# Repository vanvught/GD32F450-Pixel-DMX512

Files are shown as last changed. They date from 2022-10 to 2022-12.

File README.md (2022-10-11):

#GD32F450 Pixel DMX512

Features: 

- 16x 4 Universes pixel output
- 2x  1 Universe DMX output
- EEPROM for storing the configuration
- 1x I2C (display)
- 1x SPI
- 2x UART (WiFi , Bluetooth)

Firmware: [https://github.com/vanvught/GD32F450VI-DMX512-PIXEL](https://github.com/vanvught/GD32F450VI-DMX512-PIXEL)

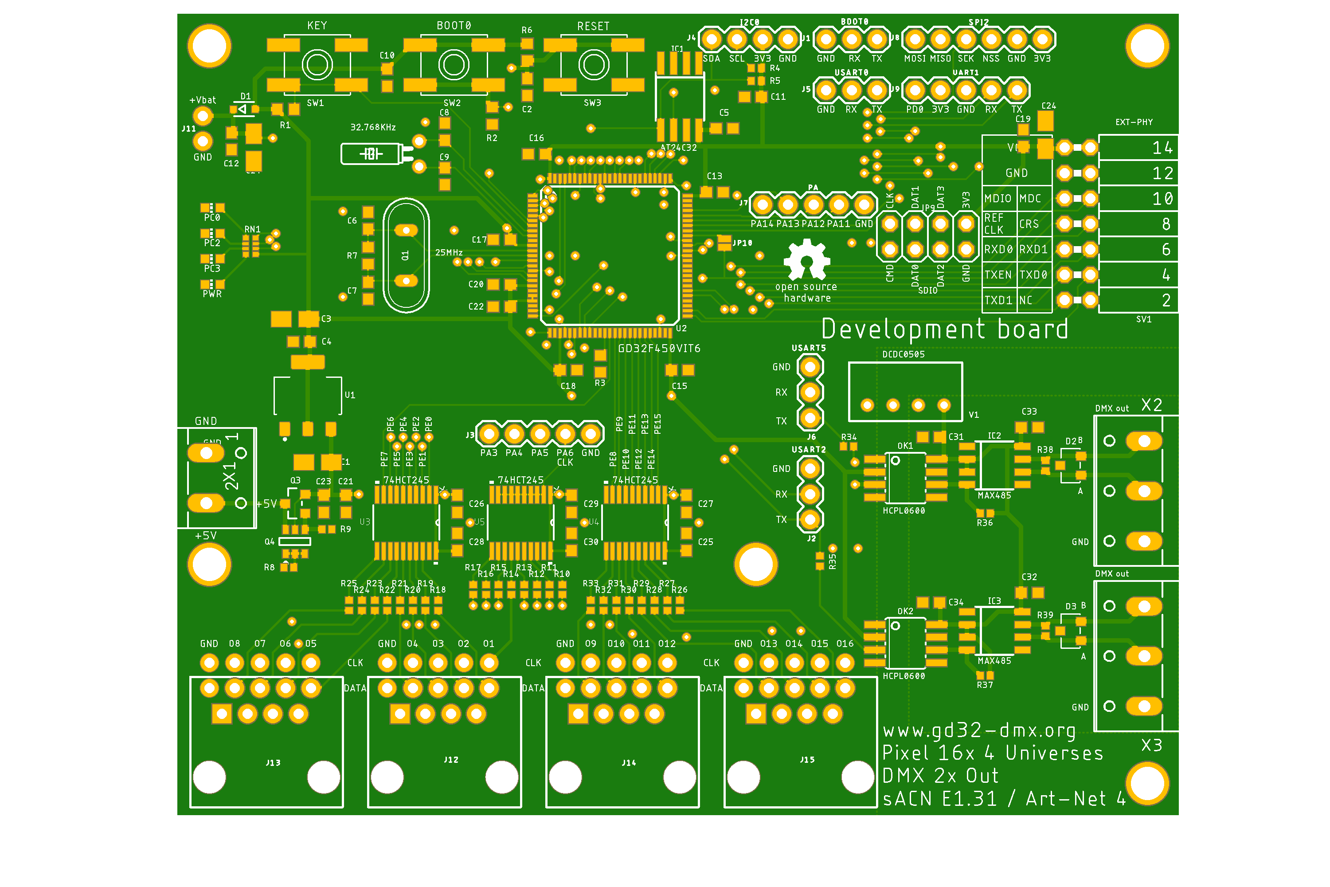
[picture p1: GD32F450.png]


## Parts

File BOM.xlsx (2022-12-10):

Qty | Designator | Footprint | Comment | LCSC Part #
4 | C1, C3, C14, C24 | A/3216-18R | 10uF | C7171
26 | C2, C4, C5, C10, C11, C12, C13, C15, C16, C17, C18, C19, C20, C22,C21, C23 , C25, C26, C27, C28, C29, C30, C31, C32, C33, C34 | C0603 | 100n | C14663
2 | C6, C7 | C0603 | 20pF | C1648
2 | C8, C9 | C0603 | 10pF | C1634
1 | D1 | SOD323-R | 1N5819 | C191023
2 | D2, D3 | SOT23-3 | PSM712-LF-T7 | C32677
1 | IC1 | SO-08M | AT24C32 | C2688466
2 | IC2, IC3 | D_R-PDSO-G8 | MAX485 | C23492
4 | LED1, LED2 , LED3, LED4 | CHIP-LED0603 | CHIP-LED0603 | C72043
2 | OK1, OK2 | SOIC08 | HCPL0600 | C393524
1 | Q3 | DIODES_INC._DMG2305UX-13_0 | DMG2305UX | C150470
1 | Q4 | DIODES_DMMT5401-7-F_0 | DMMT5401-7-F_0_0 | C154733
4 | R1, R2, R3, R6 | R0603 | 10K | C25804
24 | R10, R11, R12, R13, R14, R15, R16, R17, R18, R19, R20, R21, R22, R23, R24, R25, R26, R27, R28, R29, R30, R31, R32, R33 | R0402 | 100 | C25076
2 | R38, R39 | R0402 | 120 | C25079
2 | R34, R35 | R0402 | 470 | C25117
4 | R4, R5, R36, R37 | R0402 | 4K7 | C25900
1 | R7 | R0603 | 1M | C22935
1 | R8 | R0402 | 10K | C25744
1 | R9 | R0402 | 47K | C25792
1 | RN1 | 4X0402ARV341 | 2K | C44891
3 | SW1, SW2, SW3 | EVQ-Q2 | SPST 6*6mm Tactile Switch | C221880
1 | U1 | SOT23-5 | AMS1117-3.3 | C6186
1 | U2 | LQFP100 | GD32F450VIT6 | C98441
2 | U3, U4, U5 | PW20 | 74HCT245 | C10910
95

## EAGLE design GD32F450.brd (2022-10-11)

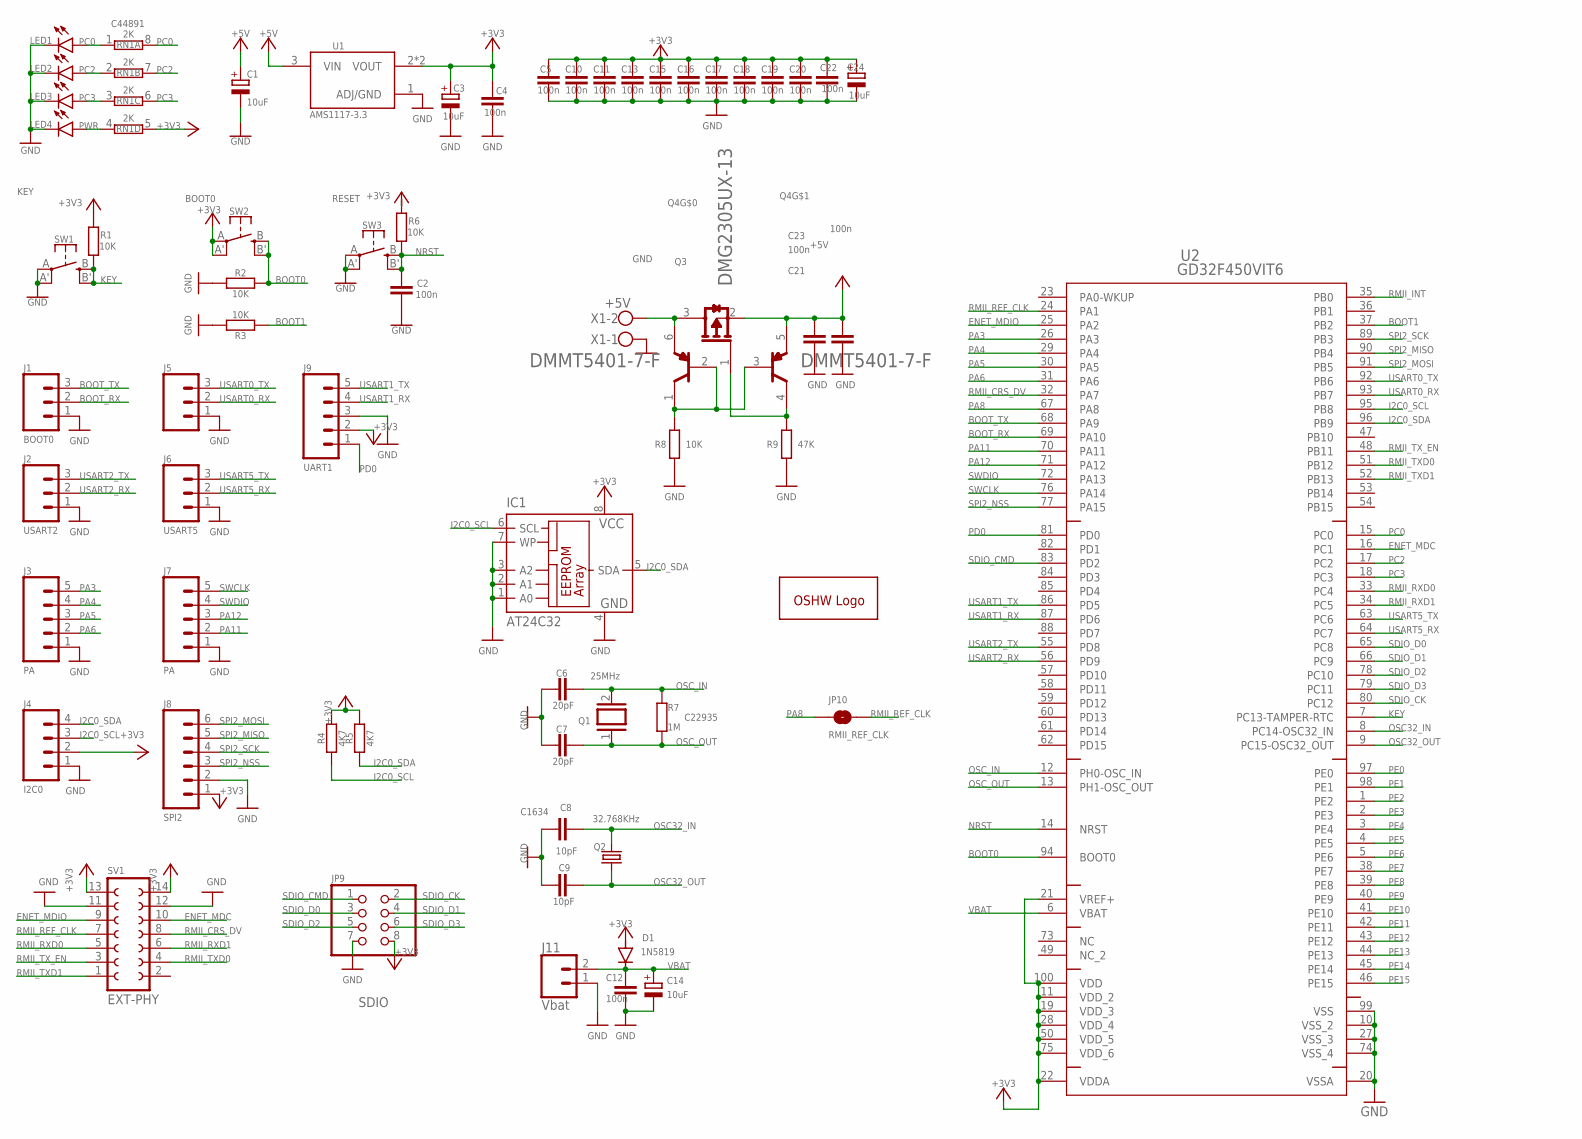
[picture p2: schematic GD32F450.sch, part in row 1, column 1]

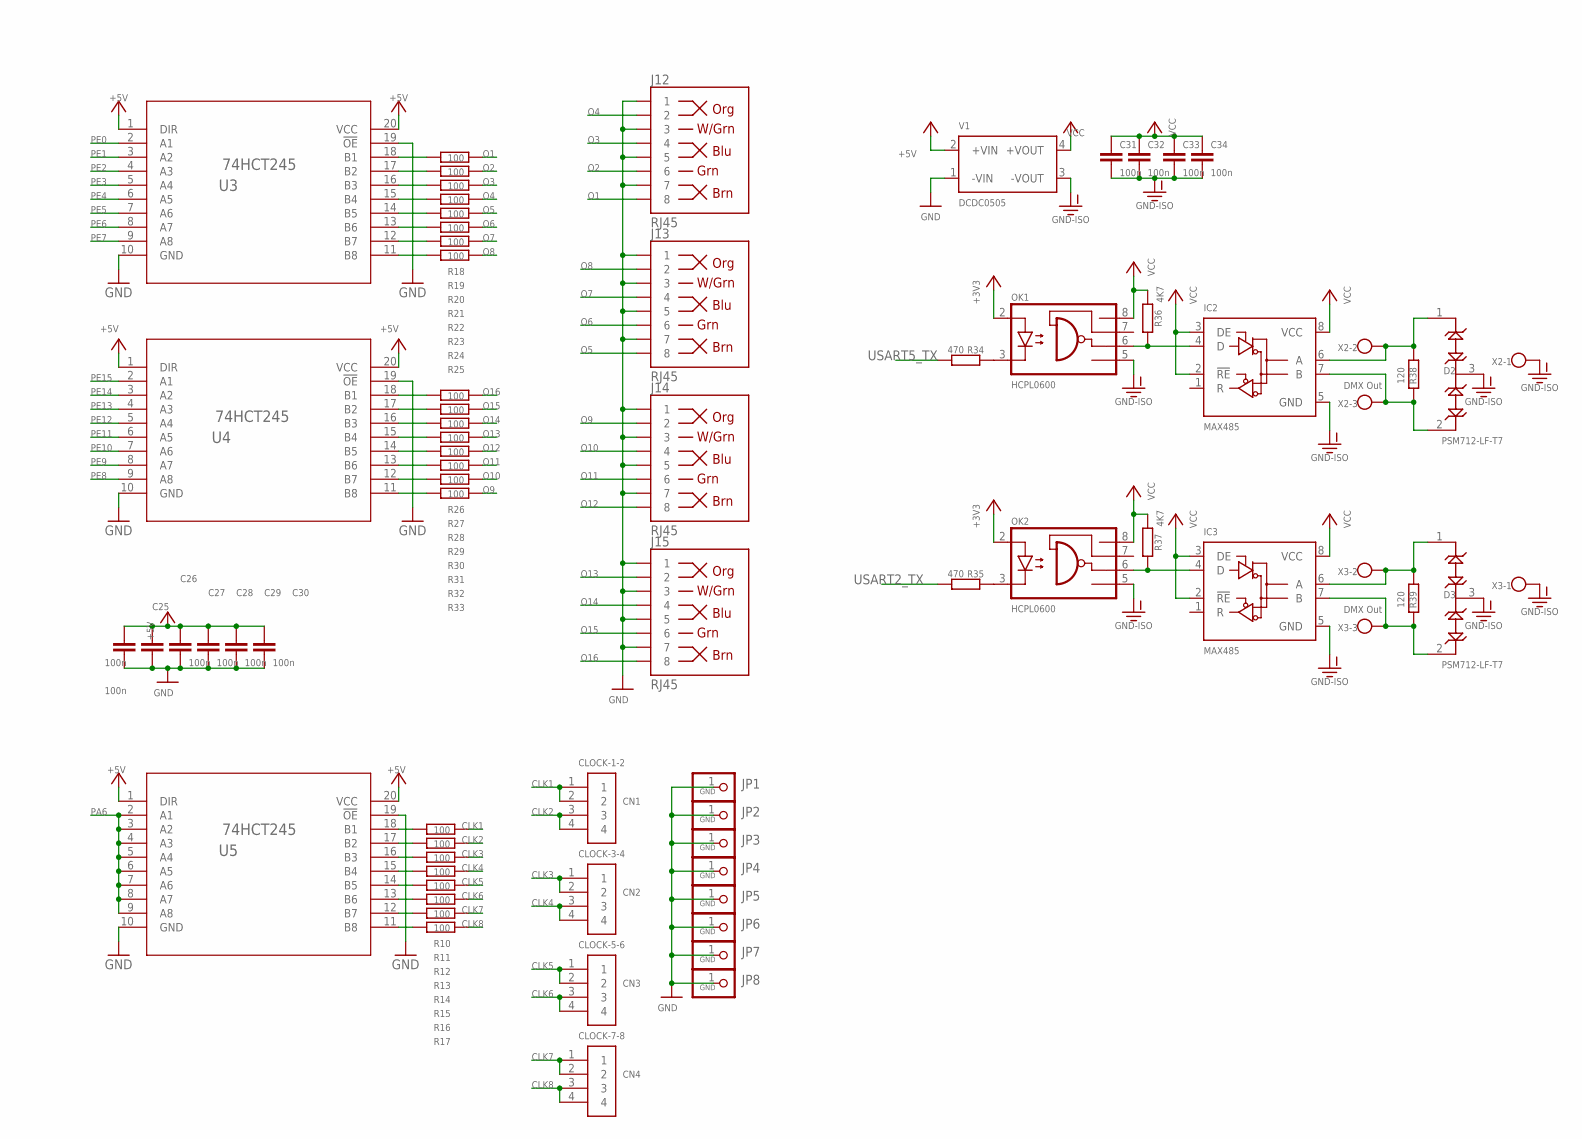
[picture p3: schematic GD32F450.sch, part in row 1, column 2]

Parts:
C1, C3, C14, C24: 10uF; A/3216-18R; JLCPCB C7171
C2, C4, C5, C10, C11, C12, C13, C15, C16, C17, C18, C19, C20, C22, C25, C26, C27, C28, C29, C30, C31, C32, C33, C34: 100n; C0603; JLCPCB C14663
C6, C7: 20pF; C0603; JLCPCB C1648
C8, C9: 10pF; C0603; JLCPCB C1634
C21, C23: 100n; C0603
CN1: CLOCK-1-2; 1X04-CLEANBIG
CN2: CLOCK-3-4; 1X04-CLEANBIG
CN3: CLOCK-5-6; 1X04-CLEANBIG
CN4: CLOCK-7-8; 1X04-CLEANBIG
D1: 1N5819; SOD323-R; JLCPCB C191023
D2, D3: PSM712-LF-T7; SOT23-3; JLCPCB C32677
GOLD_ORB_SM1: OSHWLOGOLOGO5MM; OSHW_5MM
IC1: AT24C32; SO-08M
IC2, IC3: MAX485; D_R-PDSO-G8; JLCPCB C23492
J1: BOOT0; 1X03
J2: USART2; 1X03
J3, J7: PA; 1X05
J4: I2C0; 1X04
J5: USART0; 1X03
J6: USART5; 1X03
J8: SPI2; 1X06
J9: UART1; 1X05
J11: Vbat; 1X02_NO_SILK
J12, J13, J14, J15: RJ45; RJ45-8
JP1, JP2, JP3, JP4, JP5, JP6, JP7, JP8: GND; 1X01-CLEANBIG
JP9: SDIO; 2X04
JP10: RMII_REF_CLK; SMT-JUMPER_2_NO_NO-SILK
LED1: PC0; CHIP-LED0603
LED2: PC2; CHIP-LED0603
LED3: PC3; CHIP-LED0603
LED4: PWR; CHIP-LED0603
OK1, OK2: HCPL0600; SOIC08; JLCPCB C393524
Q1: 25MHz; QS
Q2: 32.768KHz; TC26H
Q3: DMG2305UX; DIODES_INC._DMG2305UX-13_0
Q4: DMMT5401; DIODES_DMMT5401-7-F_0
R1, R2, R3, R6: 10K; R0603; JLCPCB C25804
R4, R5: 4K7; R0402; JLCPCB C23162
R7: 1M; R0603; JLCPCB C22935
R8: 10K; R0402
R9: 47K; R0402
R10, R11, R12, R13, R14, R15, R16, R17, R18, R19, R20, R21, R22, R23, R24, R25, R26, R27, R28, R29, R30, R31, R32, R33: 100; R0402
R34, R35: 470; R0402; JLCPCB C25117
R36, R37: 4K7; R0402; JLCPCB C275348
R38, R39: 120; R0402; JLCPCB C25079
RN1: 2K; 4X0402ARV341; JLCPCB C44891
SV1: EXT-PHY; FE07-2W
SW1: KEY; EVQ-Q2
SW2: BOOT0; EVQ-Q2; JLCPCB C221880
SW3: RESET; EVQ-Q2
U1: AMS1117-3.3; SOT229P700X180-4N
U2: GD32F450VIT6; LQFP100
U3, U4, U5: 74HCT245; PW20
V1: DCDC0505; TME
X1: +5V; W237-102
X2, X3: DMX Out; W237-103

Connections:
+3V3: C3.+, C4.1, C5.1, C10.1, C11.1, C13.1, C15.1, C16.1, C17.1, C18.1, C19.1, C20.1, C22.1, C24.+, D1.A, IC1.8 (VCC), J4.2, J8.1, J9.2, JP9.8, OK1.2 (A), OK2.2 (A), R1.2, R4.2, R5.2, R6.2, RN1.5 (2), SV1.13, SV1.14, SW2.A, SW2.A' (P1), U1.2 (VOUT), U1.4 (VOUT), U2.11 (VDD_2), U2.19 (VDD_3), U2.21 (VREF+), U2.22 (VDDA), U2.28 (VDD_4), U2.50 (VDD_5), U2.75 (VDD_6), U2.100 (VDD)
+5V: C1.+, C21.1, C23.1, C25.1, C26.1, C27.1, C28.1, C29.1, C30.1, Q3.2 (S), Q4.5 (E2), U1.3 (VIN), U3.1 (DIR), U3.20 (VCC), U4.1 (DIR), U4.20 (VCC), U5.1 (DIR), U5.20 (VCC), V1.2 (+VIN)
BOOT0: R2.2, SW2.B (S), SW2.B' (S1), U2.94 (BOOT0)
BOOT1: R3.1, U2.37 (PB2)
BOOT_RX: J1.2, U2.69 (PA10)
BOOT_TX: J1.3, U2.68 (PA9)
CLK1: CN1.1, CN1.2, R10.2
CLK2: CN1.3, CN1.4, R11.2
CLK3: CN2.1, CN2.2, R12.2
CLK4: CN2.3, CN2.4, R13.2
CLK5: CN3.1, CN3.2, R14.2
CLK6: CN3.3, CN3.4, R15.2
CLK7: CN4.1, CN4.2, R16.2
CLK8: CN4.3, CN4.4, R17.2
ENET_MDC: SV1.10, U2.16 (PC1)
ENET_MDIO: SV1.9, U2.25 (PA2)
GND: C1.-, C2.2, C3.-, C4.2, C5.2, C6.1, C7.1, C8.1, C9.1, C10.2, C11.2, C12.2, C13.2, C14.-, C15.2, C16.2, C17.2, C18.2, C19.2, C20.2, C21.2, C22.2, C23.2, C24.-, C25.2, C26.2, C27.2, C28.2, C29.2, C30.2, IC1.1 (A0), IC1.2 (A1), IC1.3 (A2), IC1.4 (GND), IC1.7 (WP), J1.1, J2.1, J3.1, J4.1, J5.1, J6.1, J7.1, J8.2, J9.3, J11.1, J12.1, J12.3, J12.5, J12.7, J13.1, J13.3, J13.5, J13.7, J14.1, J14.3, J14.5, J14.7, J15.1, J15.3, J15.5, J15.7, JP1.1, JP2.1, JP3.1, JP4.1, JP5.1, JP6.1, JP7.1, JP8.1, JP9.7, LED1.C, LED2.C, LED3.C, LED4.C, R2.1, R3.2, R8.1, R9.1, SV1.11, SV1.12, SW1.A, SW1.A' (P1), SW3.A, SW3.A' (P1), U1.1 (ADJ/GND), U2.10 (VSS_2), U2.20 (VSSA), U2.27 (VSS_3), U2.74 (VSS_4), U2.99 (VSS), U3.10 (GND), U3.19 (!OE), U4.10 (GND), U4.19 (!OE), U5.10 (GND), U5.19 (!OE), V1.1 (-VIN), X1.1
GND-ISO: C31.2, C32.2, C33.2, C34.2, D2.3, D3.3, IC2.5 (GND), IC3.5 (GND), OK1.5 (GND), OK2.5 (GND), V1.3 (-VOUT), X2.1, X3.1
I2C0_SCL: IC1.6 (SCL), J4.3, R4.1, U2.95 (PB8)
I2C0_SDA: IC1.5 (SDA), J4.4, R5.1, U2.96 (PB9)
KEY: R1.1, SW1.B (S), SW1.B' (S1), U2.7 (PC13-TAMPER-RTC)
unnamed: R18.1, U3.18 (B1)
unnamed: Q4.1 (C1), Q4.2 (B1), Q4.3 (B2), R8.2
unnamed: R19.1, U3.17 (B2)
unnamed: R20.1, U3.16 (B3)
unnamed: R21.1, U3.15 (B4)
unnamed: R22.1, U3.14 (B5)
unnamed: R23.1, U3.13 (B6)
unnamed: R24.1, U3.12 (B7)
unnamed: R25.1, U3.11 (B8)
unnamed: LED1.A, RN1.1
unnamed: LED2.A, RN1.2 (1)
unnamed: R26.1, U4.18 (B1)
unnamed: R27.1, U4.17 (B2)
unnamed: R28.1, U4.16 (B3)
unnamed: R29.1, U4.15 (B4)
unnamed: R30.1, U4.14 (B5)
unnamed: R31.1, U4.13 (B6)
unnamed: R32.1, U4.12 (B7)
unnamed: R33.1, U4.11 (B8)
unnamed: IC2.4 (D), OK1.6 (VO), R36.2
unnamed: OK1.3 (C), R34.2
unnamed: IC3.4 (D), OK2.6 (VO), R37.2
unnamed: OK2.3 (C), R35.2
unnamed: D2.1, IC2.6 (A), R38.1, X2.2
unnamed: LED3.A, RN1.3 (1)
unnamed: LED4.A, RN1.4 (1)
unnamed: D2.2, IC2.7 (B), R38.2, X2.3
unnamed: D3.2, IC3.7 (B), R39.2, X3.3
unnamed: D3.1, IC3.6 (A), R39.1, X3.2
unnamed: Q3.1 (G), Q4.4 (C2), R9.2
unnamed: Q3.3 (D), Q4.6 (E1), X1.2
unnamed: R10.1, U5.18 (B1)
unnamed: R11.1, U5.17 (B2)
unnamed: R12.1, U5.16 (B3)
unnamed: R13.1, U5.15 (B4)
unnamed: R14.1, U5.14 (B5)
unnamed: R15.1, U5.13 (B6)
unnamed: R16.1, U5.12 (B7)
unnamed: R17.1, U5.11 (B8)
NRST: C2.1, R6.1, SW3.B (S), SW3.B' (S1), U2.14 (NRST)
O1: J12.8, R18.2
O2: J12.6, R19.2
O3: J12.4, R20.2
O4: J12.2, R21.2
O5: J13.8, R22.2
O6: J13.6, R23.2
O7: J13.4, R24.2
O8: J13.2, R25.2
O9: J14.2, R33.2
O10: J14.4, R32.2
O11: J14.6, R31.2
O12: J14.8, R30.2
O13: J15.2, R29.2
O14: J15.4, R28.2
O15: J15.6, R27.2
O16: J15.8, R26.2
OSC32_IN: C8.2, Q2.2, U2.8 (PC14-OSC32_IN)
OSC32_OUT: C9.2, Q2.1, U2.9 (PC15-OSC32_OUT)
OSC_IN: C6.2, Q1.2, R7.2, U2.12 (PH0-OSC_IN)
OSC_OUT: C7.2, Q1.1, R7.1, U2.13 (PH1-OSC_OUT)
PA3: J3.5, U2.26 (PA3)
PA4: J3.4, U2.29 (PA4)
PA5: J3.3, U2.30 (PA5)
PA6: J3.2, U2.31 (PA6), U5.2 (A1), U5.3 (A2), U5.4 (A3), U5.5 (A4), U5.6 (A5), U5.7 (A6), U5.8 (A7), U5.9 (A8)
PA8: JP10.1, U2.67 (PA8)
PA11: J7.2, U2.70 (PA11)
PA12: J7.3, U2.71 (PA12)
PC0: RN1.8 (2), U2.15 (PC0)
PC2: RN1.7 (2), U2.17 (PC2)
PC3: RN1.6 (2), U2.18 (PC3)
PD0: J9.1, U2.81 (PD0)
PE0: U2.97 (PE0), U3.2 (A1)
PE1: U2.98 (PE1), U3.3 (A2)
PE2: U2.1 (PE2), U3.4 (A3)
PE3: U2.2 (PE3), U3.5 (A4)
PE4: U2.3 (PE4), U3.6 (A5)
PE5: U2.4 (PE5), U3.7 (A6)
PE6: U2.5 (PE6), U3.8 (A7)
PE7: U2.38 (PE7), U3.9 (A8)
PE8: U2.39 (PE8), U4.9 (A8)
PE9: U2.40 (PE9), U4.8 (A7)
PE10: U2.41 (PE10), U4.7 (A6)
PE11: U2.42 (PE11), U4.6 (A5)
PE12: U2.43 (PE12), U4.5 (A4)
PE13: U2.44 (PE13), U4.4 (A3)
PE14: U2.45 (PE14), U4.3 (A2)
PE15: U2.46 (PE15), U4.2 (A1)
RMII_CRS_DV: SV1.8, U2.32 (PA7)
RMII_INT: U2.35 (PB0)
RMII_REF_CLK: JP10.2, SV1.7, U2.24 (PA1)
RMII_RXD0: SV1.5, U2.33 (PC4)
RMII_RXD1: SV1.6, U2.34 (PC5)
RMII_TXD0: SV1.4, U2.51 (PB12)
RMII_TXD1: SV1.1, U2.52 (PB13)
RMII_TX_EN: SV1.3, U2.48 (PB11)
SDIO_CK: JP9.2, U2.80 (PC12)
SDIO_CMD: JP9.1, U2.83 (PD2)
SDIO_D0: JP9.3, U2.65 (PC8)
SDIO_D1: JP9.4, U2.66 (PC9)
SDIO_D2: JP9.5, U2.78 (PC10)
SDIO_D3: JP9.6, U2.79 (PC11)
SPI2_MISO: J8.5, U2.90 (PB4)
SPI2_MOSI: J8.6, U2.91 (PB5)
SPI2_NSS: J8.3, U2.77 (PA15)
SPI2_SCK: J8.4, U2.89 (PB3)
SWCLK: J7.5, U2.76 (PA14)
SWDIO: J7.4, U2.72 (PA13)
USART0_RX: J5.2, U2.93 (PB7)
USART0_TX: J5.3, U2.92 (PB6)
USART1_RX: J9.4, U2.87 (PD6)
USART1_TX: J9.5, U2.86 (PD5)
USART2_RX: J2.2, U2.56 (PD9)
USART2_TX: J2.3, R35.1, U2.55 (PD8)
USART5_RX: J6.2, U2.64 (PC7)
USART5_TX: J6.3, R34.1, U2.63 (PC6)
VBAT: C12.1, C14.+, D1.C, J11.2, U2.6 (VBAT)
VCC: C31.1, C32.1, C33.1, C34.1, IC2.2 (!RE), IC2.3 (DE), IC2.8 (VCC), IC3.2 (!RE), IC3.3 (DE), IC3.8 (VCC), OK1.8 (VCC), OK2.8 (VCC), R36.1, R37.1, V1.4 (+VOUT)

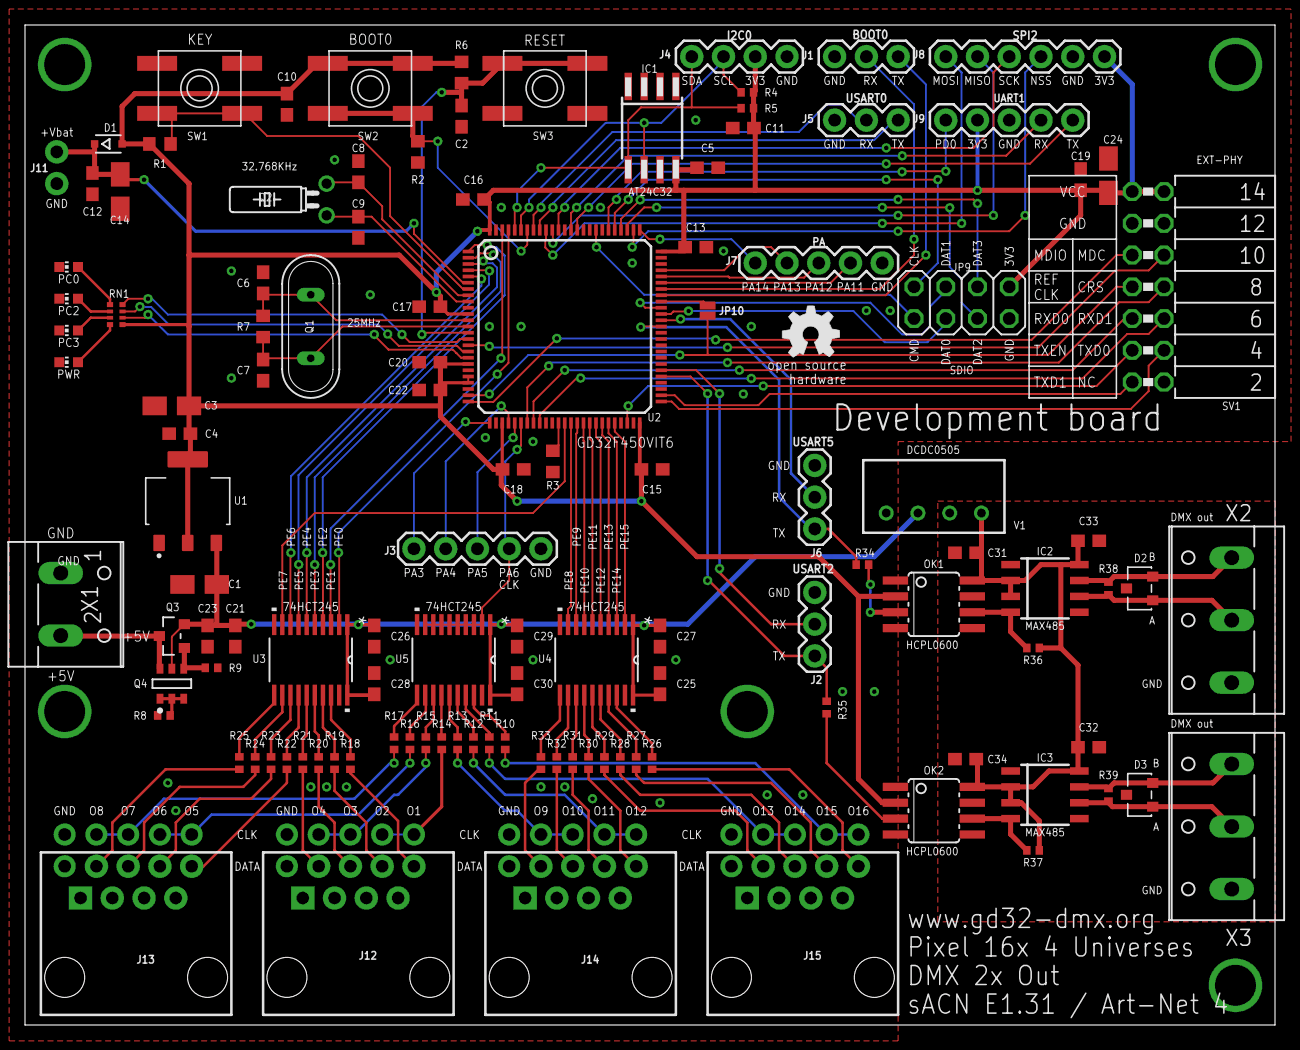
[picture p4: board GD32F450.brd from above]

Board: 2 copper layers, 100.0 x 80.0 mm, 132 parts (0 on the bottom side), 137 nets.

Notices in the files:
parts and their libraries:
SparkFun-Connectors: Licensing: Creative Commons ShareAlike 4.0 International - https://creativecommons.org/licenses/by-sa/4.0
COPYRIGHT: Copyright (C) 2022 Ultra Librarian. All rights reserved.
